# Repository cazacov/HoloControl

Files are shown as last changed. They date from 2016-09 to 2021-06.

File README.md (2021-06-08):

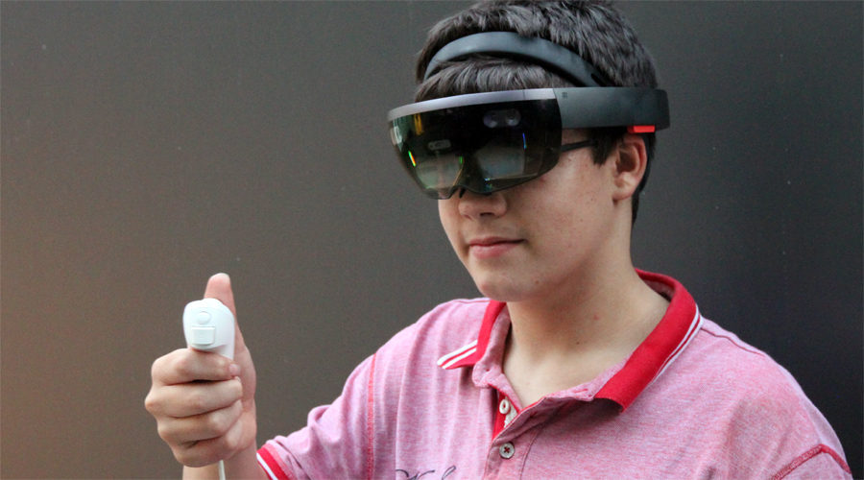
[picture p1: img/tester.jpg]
My son testing the new controller


# HoloControl
HoloLens input device based on Wii Nunchuk controller.
- Adds two buttons and joystick functionality
- Wireless connection over Bluetooth
- Low latency, reaction time < 1/20 second
- Easy to use in Unity, no external dependencies

## Demo Video

(https://www.youtube.com/watch?v=75GZE48Ib2U)

## How it works

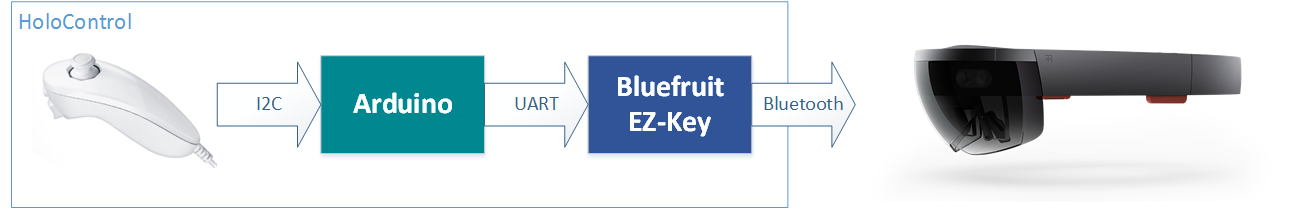
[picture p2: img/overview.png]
Overview
[](https://raw.githubusercontent.com/cazacov/HoloControl/master/img/overview.png "Overview")

- Arduino board reads button state from nunchuk over I2C protocol.
- Arduno translates key press events in [USB HID codes](http://www.freebsddiary.org/APC/usb_hid_usages.php) and sends them to EZ-Key board over serial interface.
- Bluefruit EZ-Key board appears like an external keyboard in the list of available Bluetooth devices on the HoloLens.
- Standard Bluetooth pairing, no PIN required. If something goes wrong there is Pair button on the EZ-Key board to restart the connection.
- For Unity scripts the HoloControler looks like normal key press events coming from a keyboard.

First prototype

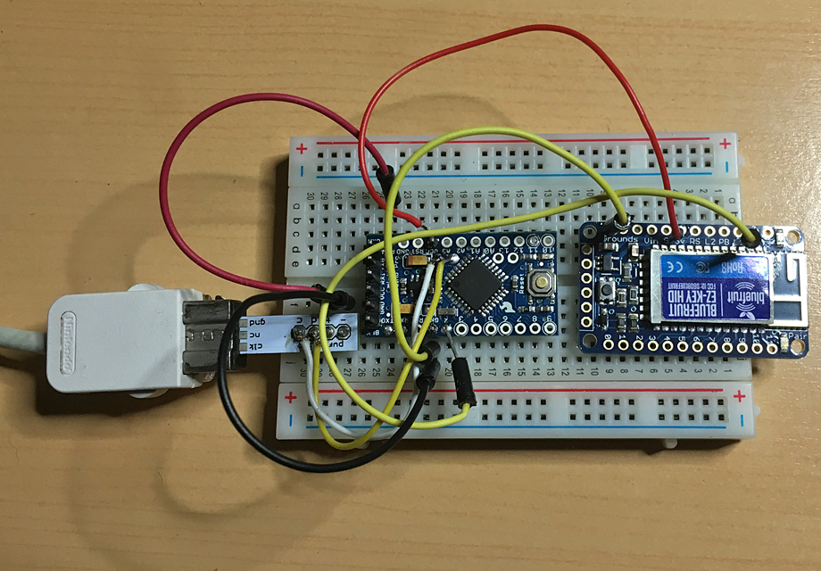
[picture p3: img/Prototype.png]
Prototype
[](https://raw.githubusercontent.com/cazacov/HoloControl/master/img/Prototype.png "Prototype")

## Hardware

### Parts list
| Part | Price in EU | Comment |
| --- | --- | --- |
| Wii Nunchuk | 10 € | Got one in perfect condition on Ebay |
| Arduino Mini 3.3V/8MHz | 9.50 € | Reads data from the Nunchuk |
| Bluefruit EZ-Key | 21 € | Bluetooth HID Keyboard Controller |

You will also need FTDI cable to program Arduino Mini. It's also possible to [use regular Arduino as programmer](https://www.arduino.cc/en/Guide/ArduinoMini).

### Wiring

Wired version

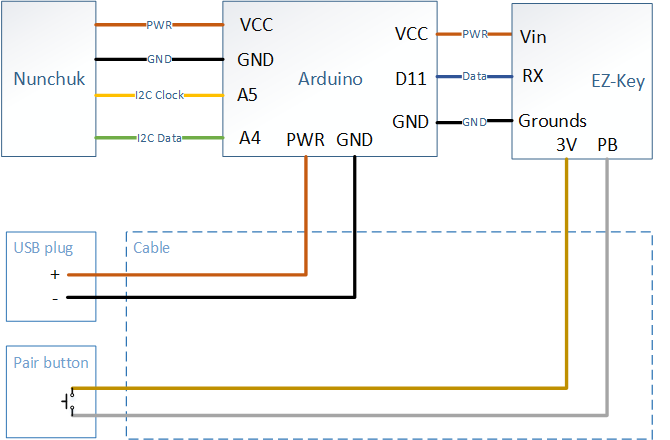
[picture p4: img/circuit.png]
Circuit diagram
[](https://raw.githubusercontent.com/cazacov/HoloControl/master/img/circuit.png "Circuit diagram")

It's also possible to make it completely mobile by adding LiPo accumulator and charge controller, but then you'll need a 3D printer to print bigger case.

Arduino stacked on the top of EZ-Key board. I put a piece of plastic between boards for electrical isolation.

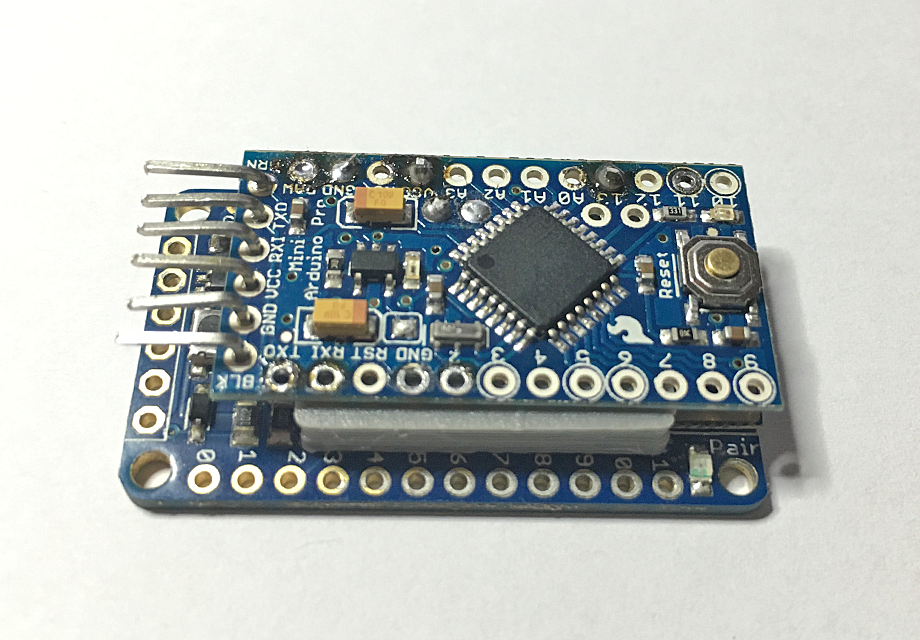
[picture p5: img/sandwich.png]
Boards
[](https://raw.githubusercontent.com/cazacov/HoloControl/master/img/sandwich.png "Boards")

Nunchuk board pinout.

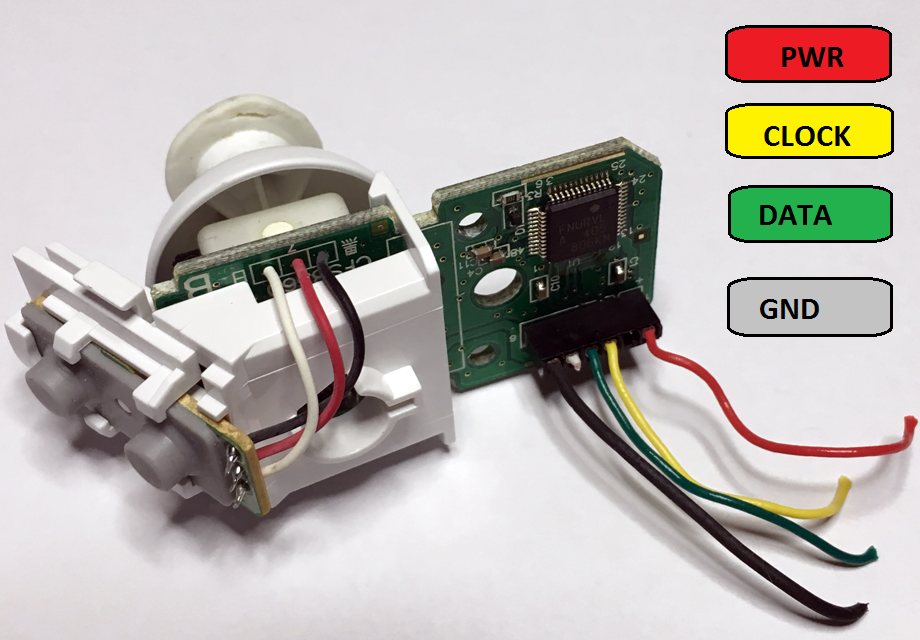
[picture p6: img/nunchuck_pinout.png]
Nunchuk board
[](https://raw.githubusercontent.com/cazacov/HoloControl/master/img/nunchuck_pinout.png "Nunchuk board")

Electronics nicely fits into original nunchuk case.

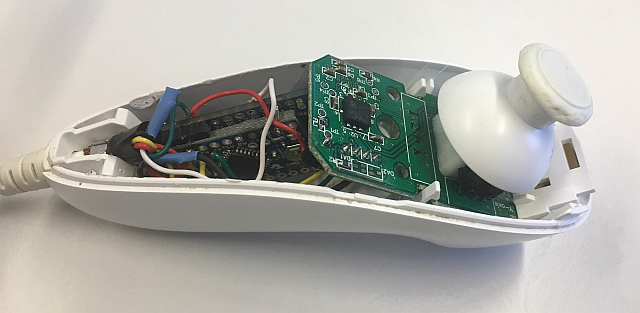
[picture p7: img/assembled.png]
Assembled controller
[](https://raw.githubusercontent.com/cazacov/HoloControl/master/img/assembled.png "Assembled controller")

## Firmware

Arduino sources are in the "Arduino" folder.

The easiest way to program Arduino Mini is using FTDI cable. It's also possible to use USB<->Serial adapter or Arduino UNO as programming device.

Be sure to choose correct board type in the Arduino IDE

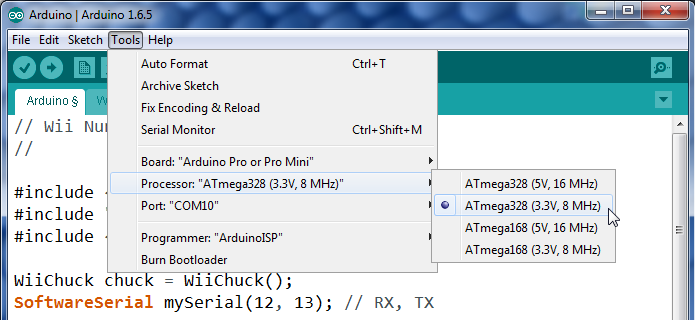
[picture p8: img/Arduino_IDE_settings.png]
Arduino IDE settings
[](https://raw.githubusercontent.com/cazacov/HoloControl/master/img/Arduino_IDE_settings.png "Arduino IDE settings")

## Using in Unity

The controller simulates keys strokes on a Bluetooth keyboard. Joystick directions are translated in A, D, W, S keys. Z button is mapped to Return and C button to Escape. 

You can get key state with the standard UnityEngine.Input class:

```csharp
if (UnityEngine.Input.GetKey(KeyCode.A))
{
	// Joystick left
	...
}

if (UnityEngine.Input.GetKey(KeyCode.D))
{
	// Joystick right
	...
}
```

Demo Unity project is included.

## Wired version
Still needs cable for power supply (USB plug A).

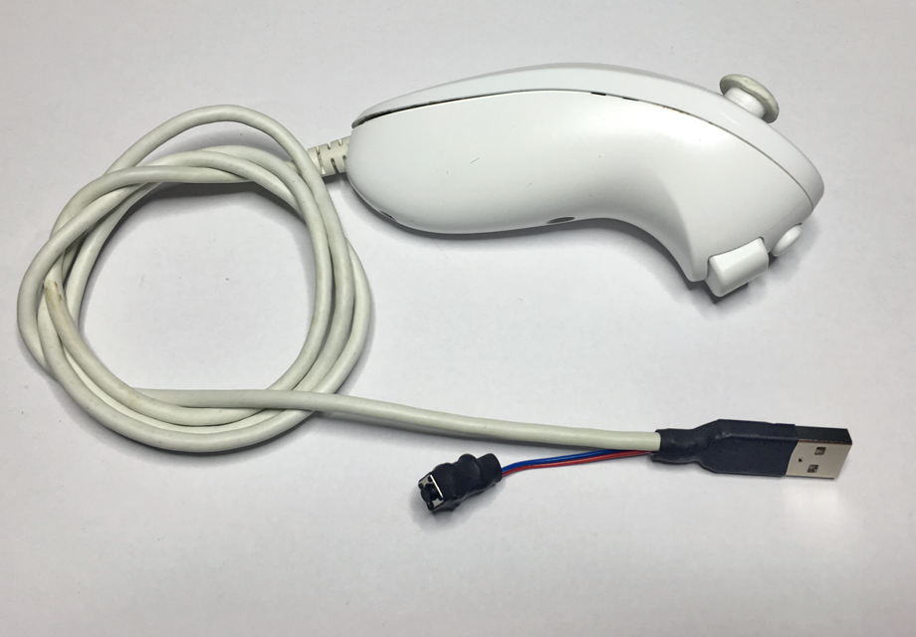
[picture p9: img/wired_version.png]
HoloController
[](https://raw.githubusercontent.com/cazacov/HoloControl/master/img/wired_version.png "HoloController")

## Wireless version

Adds LiPo accumulator and charging controller.

Coming soon.

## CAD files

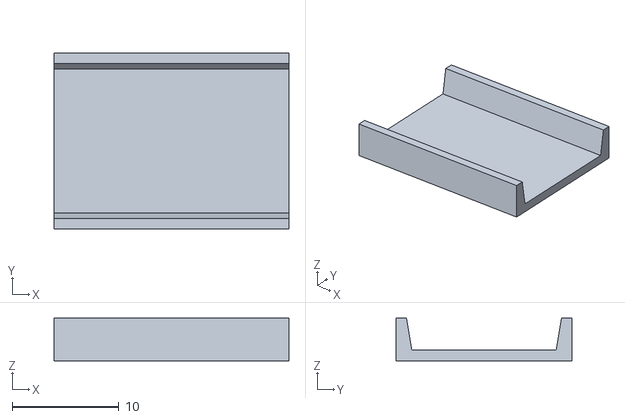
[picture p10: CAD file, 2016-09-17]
3d models/ezkey_spacer.stl
22.0 x 16.5 x 4.00

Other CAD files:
3d models/ezkey_spacer.blend

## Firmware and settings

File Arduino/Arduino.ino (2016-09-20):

// Arduino Mini pinout
// https://cdn.sparkfun.com/datasheets/Dev/Arduino/Boards/ProMini8MHzv1.pdf

// Bluefruit EZ-Key pinout
// https://learn.adafruit.com/introducing-bluefruit-ez-key-diy-bluetooth-hid-keyboard/pinouts

// Wii nunchuk pinout
// https://oscarliang.com/wii-nunchuck-arduino-tutorial/

// Wii Nunchuck connection
// GND -> GND Arduino
// PWR -> VCC
// SDA (data)  -> A4
// SCL (clock) -> A5

// EZ-Key connection
// Grounds -> GND
// 3V -> VCC
// RX -> 11 (digital)

#include <Wire.h>
#include "WiiChuck.h"
#include <SoftwareSerial.h>

WiiChuck chuck = WiiChuck();
SoftwareSerial bt(3, 11); // RX, TX

// Arduino IDE settings:
// Tools->Board: "Arduino Pro or Pro Mini"
// Tools->Processor: "ATmega328 (3.3V, 8MHz)

void setup() {
  Serial.begin(9600);   // be sure that 8MHz board is selected in Arduino IDE
  bt.begin(9600);       // otherwise the transfer speed will be wrong
  chuck.begin();
  chuck.update();
}

uint8_t lastSent[6] = {0,0,0,0,0,0};

// the loop function runs over and over again forever
void loop() {
  delay(20);
  chuck.update(); 

  uint8_t keyFlags[6] = {0,0,0,0,0,0};
  short keysPressed = 0;

  // USB HID codes
  // http://www.freebsddiary.org/APC/usb_hid_usages.php

  // Set USB HID flags
  if (chuck.buttonZ)
  {
    keyFlags[keysPressed++] = 0x28; // Keyboard Return (ENTER)
  }
  if (chuck.buttonC)
  {
    keyFlags[keysPressed++] = 0x29;  // Keyboard ESCAPE
  }
  if (chuck.readJoyX() < -60)
  {
    keyFlags[keysPressed++] = 0x04; // Keyboard a and A
  }
  if (chuck.readJoyX() > 60)
  {
    keyFlags[keysPressed++] = 0x07; // Keyboard d and D
  }
  if (chuck.readJoyY() < -60)
  {
    keyFlags[keysPressed++] = 0x16; //Keyboard s and S
  }
  if (chuck.readJoyY() > 60)
  {
    keyFlags[keysPressed++] = 0x1A;  // Keyboard w and W
  }

  // add trailing 0
  while (keysPressed < 6)
  {
    keyFlags[keysPressed++] = 0;
  }

  // Check if keys state changed sicne last transfer
  bool flagsChanged = false;
  for (short i = 0; i < 6; i++)
  {
    if (lastSent[i] != keyFlags[i])
    {
      flagsChanged = true;
    }
  }

  if (flagsChanged) {
    uint8_t modifiers = 0;
    
    bt.write(0xFD);         // HID report
    bt.write(modifiers);    // modifiers
    bt.write((byte)0x00);   // reserved  
    bt.write(keyFlags[0]);  // key code #1
    bt.write(keyFlags[1]);  // key code #2
    bt.write(keyFlags[2]);  // key code #3
    bt.write(keyFlags[3]);  // key code #4
    bt.write(keyFlags[4]);  // key code #5
    bt.write(keyFlags[5]);  // key code #6

    for (short i = 0; i< 6; i++)
    {
      lastSent[i] = keyFlags[i];
      Serial.print(keyFlags[i]);
      Serial.print(",");
    }
    Serial.println();
  }
}

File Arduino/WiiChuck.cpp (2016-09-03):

#include "WiiChuck.h"
#include "Arduino.h" 
#include <Wire.h>

// these may need to be adjusted for each nunchuck for calibration
#define ZEROX 510  
#define ZEROY 490
#define ZEROZ 460
#define RADIUS 210  // probably pretty universal

#define DEFAULT_ZERO_JOY_X 124
#define DEFAULT_ZERO_JOY_Y 132

void WiiChuck::begin() {

    Wire.begin();
    cnt = 0;
    averageCounter = 0;
    // instead of the common 0x40 -> 0x00 initialization, we
    // use 0xF0 -> 0x55 followed by 0xFB -> 0x00.
    // this lets us use 3rd party nunchucks (like cheap $4 ebay ones)
    // while still letting us use official oness.
    // only side effect is that we no longer need to decode bytes in _nunchuk_decode_byte
    // see http://forum.arduino.cc/index.php?topic=45924#msg333160
    //  
    Wire.beginTransmission(0x52);       // device address
    Wire.write(0xF0);
    Wire.write(0x55);
    Wire.endTransmission();
    delay(1);
    Wire.beginTransmission(0x52);
    Wire.write(0xFB);
    Wire.write(0x00);
    Wire.endTransmission();
    update();            
    for (i = 0; i<3;i++) {
        angles[i] = 0;
    }
    zeroJoyX = DEFAULT_ZERO_JOY_X;
    zeroJoyY = DEFAULT_ZERO_JOY_Y;
}

void WiiChuck::calibrateJoy() {
    zeroJoyX = joyX;
    zeroJoyY = joyY;
}

void WiiChuck::update() {

    Wire.requestFrom (0x52, 6); // request data from nunchuck
    while (Wire.available ()) {
        // receive byte as an integer
        status[cnt] = _nunchuk_decode_byte (Wire.read()); //
        cnt++;
    }
    if (cnt > 5) {
        lastZ = buttonZ;
        lastC = buttonC;
        lastJoyX = readJoyX();
        lastJoyY = readJoyY();
        //averageCounter ++;
        //if (averageCounter >= AVERAGE_N)
        //    averageCounter = 0;

        cnt = 0;
        joyX = (status[0]);
        joyY = (status[1]);
        for (i = 0; i < 3; i++) 
            //accelArray[i][averageCounter] = ((int)status[i+2] << 2) + ((status[5] & (B00000011 << ((i+1)*2) ) >> ((i+1)*2))); 
            angles[i] = (status[i+2] << 2) + ((status[5] & (B00000011 << ((i+1)*2) ) >> ((i+1)*2))); 

        //accelYArray[averageCounter] = ((int)status[3] << 2) + ((status[5] & B00110000) >> 4); 
        //accelZArray[averageCounter] = ((int)status[4] << 2) + ((status[5] & B11000000) >> 6); 

        buttonZ = !( status[5] & B00000001);
        buttonC = !((status[5] & B00000010) >> 1);
        _send_zero(); // send the request for next bytes

    }
}


float WiiChuck::readAccelX() {
   // total = 0; // accelArray[xyz][averageCounter] * FAST_WEIGHT;
    return (float)angles[0] - ZEROX;
}

float WiiChuck::readAccelY() {
    // total = 0; // accelArray[xyz][averageCounter] * FAST_WEIGHT;
    return (float)angles[1] - ZEROY;
}

float WiiChuck::readAccelZ() {
    // total = 0; // accelArray[xyz][averageCounter] * FAST_WEIGHT;
    return (float)angles[2] - ZEROZ;
}

boolean WiiChuck::zPressed() {
    return (buttonZ && ! lastZ);
}

boolean WiiChuck::cPressed() {
    return (buttonC && ! lastC);
}

// for using the joystick like a directional button
boolean WiiChuck::rightJoy(int thresh) {
    return (readJoyX() > thresh and lastJoyX <= thresh);
}

// for using the joystick like a directional button
boolean WiiChuck::leftJoy(int thresh) {
    return (readJoyX() < -thresh and lastJoyX >= -thresh);
}

// for using the joystick like a directional button
boolean WiiChuck::upJoy(int thresh) {
    return (readJoyY() > thresh and lastJoyY <= thresh);
}

// for using the joystick like a directional button
boolean WiiChuck::downJoy(int thresh) {
    return (readJoyY() < -thresh and lastJoyY >= -thresh);
}

int WiiChuck::readJoyX() {
    return (int) joyX - zeroJoyX;
}

int WiiChuck::readJoyY() {
    return (int)joyY - zeroJoyY;
}


// R, the radius, generally hovers around 210 (at least it does with mine)
// int R() {
//     return sqrt(readAccelX() * readAccelX() +readAccelY() * readAccelY() + readAccelZ() * readAccelZ());  
// }


// returns roll degrees
int WiiChuck::readRoll() {
    return (int)(atan2(readAccelX(),readAccelZ())/ M_PI * 180.0);
}

// returns pitch in degrees
int WiiChuck::readPitch() {        
    return (int) (acos(readAccelY()/RADIUS)/ M_PI * 180.0);  // optionally swap 'RADIUS' for 'R()'
}

    
byte WiiChuck::_nunchuk_decode_byte (byte x)
{
    //decode is only necessary with certain initializations 
    //x = (x ^ 0x17) + 0x17;
    return x;
}

void WiiChuck::_send_zero()
{
    Wire.beginTransmission (0x52);      // transmit to device 0x52
    Wire.write (0x00);           // sends one byte
    Wire.endTransmission ();    // stop transmitting
}

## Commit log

2016-09-17 3D models for spacer between Arduino and EZKEY borads
    [ezkey_spacer.blend, ezkey_spacer.stl]
2016-09-18 Change PIN number
